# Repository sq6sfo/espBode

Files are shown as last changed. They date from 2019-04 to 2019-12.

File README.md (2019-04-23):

# espBode
Interface between a Siglent oscilloscope and FY6800 AWG

The idea bases on solution proposed by 4x1md in https://github.com/4x1md/sds1004x_bode

Currently implemented features:
 - ESP is able to connect to a selected WiFi network and listen to oscilloscope requests
 - After ESP sends request to AWG it waits for confirmation

TODO:
 - rewrite whole thing to C++, so adding new AWGs would be easier
 - add possibility to configure SSID/PSK + IP without flashing the new SW

**!WARNING! FY6800 VCC level is 5V, so it has to be dropped somehow to 3.3V ESP may release the magic smoke otherwise.**

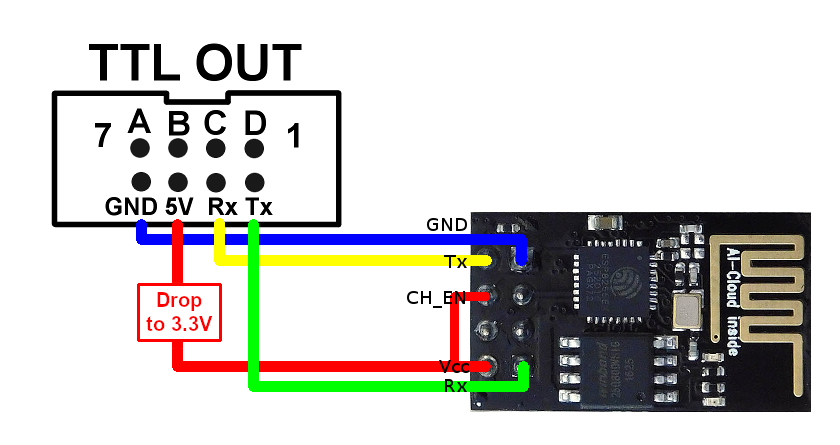
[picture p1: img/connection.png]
image test


In my configuration I've just used a yellow LED, that dropped the voltage by ~2V.
ESP consumes about 70mA, that's probably too much for a LED, but maybe it'll survive.

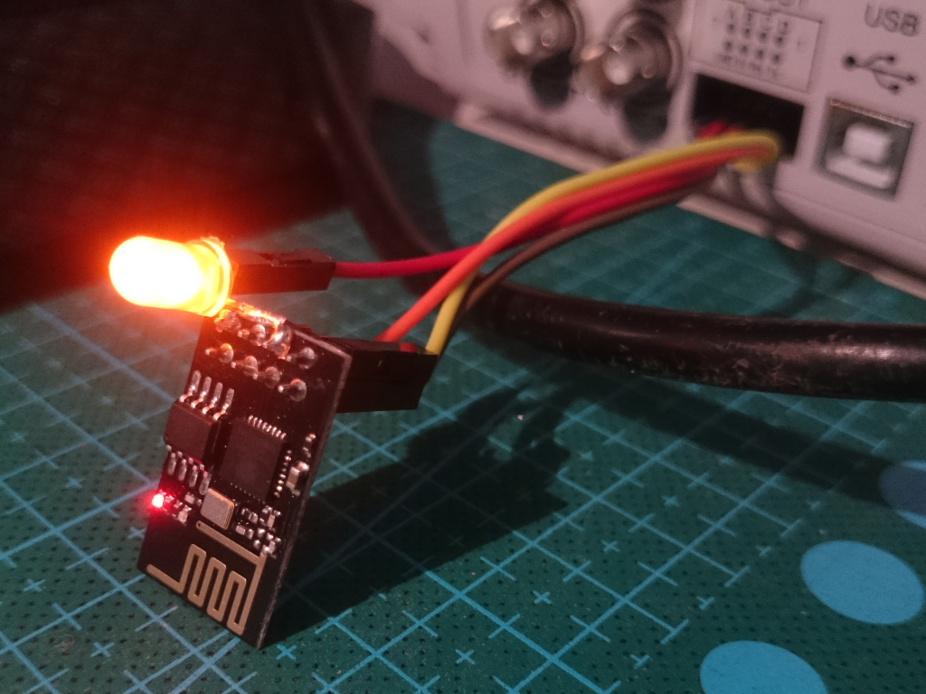
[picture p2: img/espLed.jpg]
image LED


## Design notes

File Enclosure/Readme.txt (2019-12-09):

3d printing instructions:
The enclosure consists of 3 parts.
  - The mounting plate for the ESP3266 adapter (with either heat stakes or M2x4 standoffs),
  - The actual enclosure to be used with M2x12 bolts.
  - The connector insert (has a tight fit but could also be crazy-glued to the mounting plate)

I recommend to use 0.1mm or smaller layer height so that the M2 thread is reasonably well reproduced.
The ESP adapter is cheaply available at Amazone, Banggood or Ali-Express at under $4 CDN delivered.
It has the necessary level shifters and 3.3V regulator on board an can be plugged in directly to the FY6800.
I used a small 1x4 female connector that snug fits into the printed connector insert on the bottom
side only so that the top 1x4 row of pins of the FY6800 just dangle without connection. A short ribbon
cable connects 1:1 with the adapter.

So far I am pretty happy with the current functionality developed by Jakub Stępniewicz and his collaborators.
There are a few glitches when you are operating the 8266 in AP mode. As it is not possible to connect to a static
scope ID, one needs to first make the scope use its DHCP to connect to the 8266. After that you need to switch
the scope back to static IP using the so found IP address. Havent found a smarter way of dealing with this issue.
But maybe someone has?

Another problem I found and currently investigate is with the FY6800's command for setting the amplitude. It is
correctly transmitted to the AWG but not recognized there.

Other than that, this is a great project and everybody's work on it greatly appreciated.
Keep up the good work! I may contribute more in the future as well :).

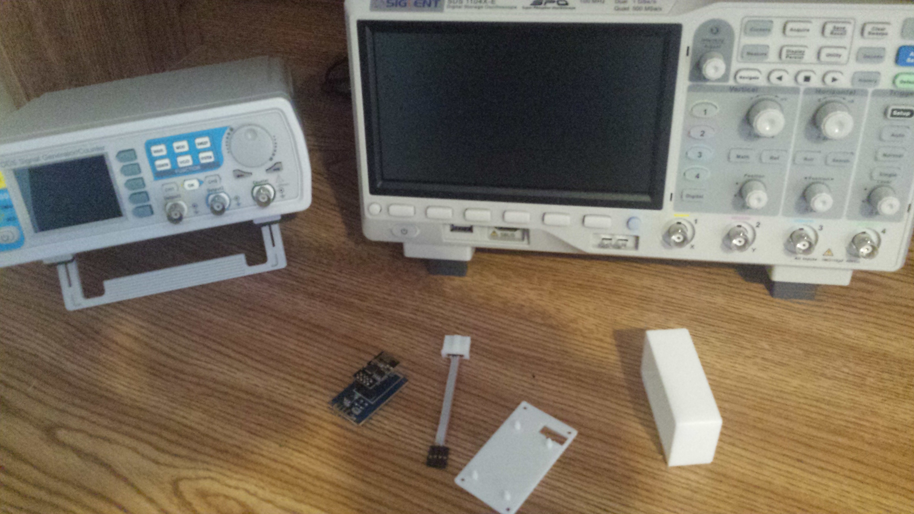
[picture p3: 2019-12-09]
Enclosure/SigFt1.jpg

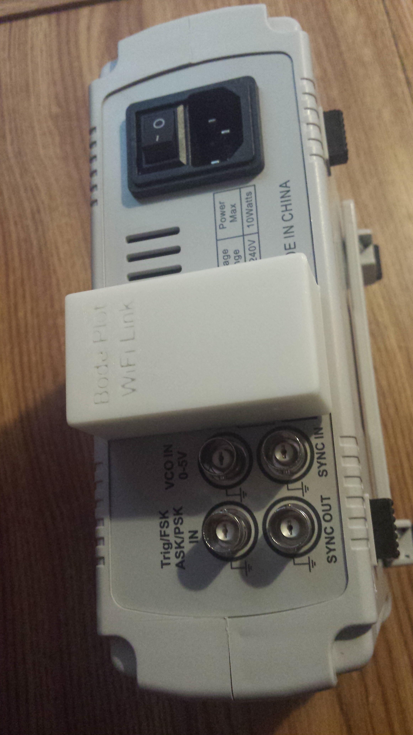
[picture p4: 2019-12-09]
Enclosure/SigFt3.jpg

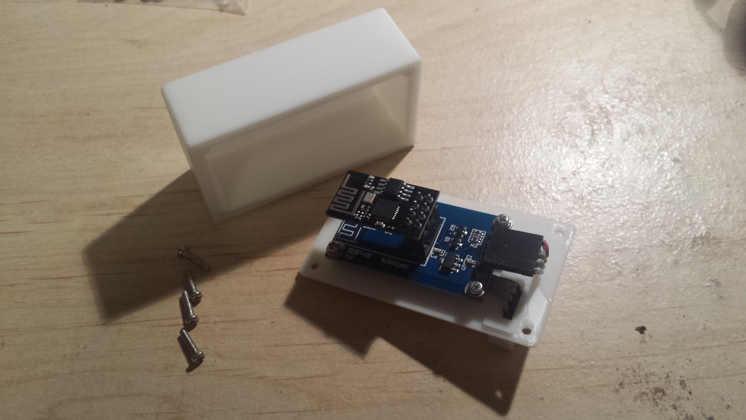
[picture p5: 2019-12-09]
Enclosure/SigFt4.jpg

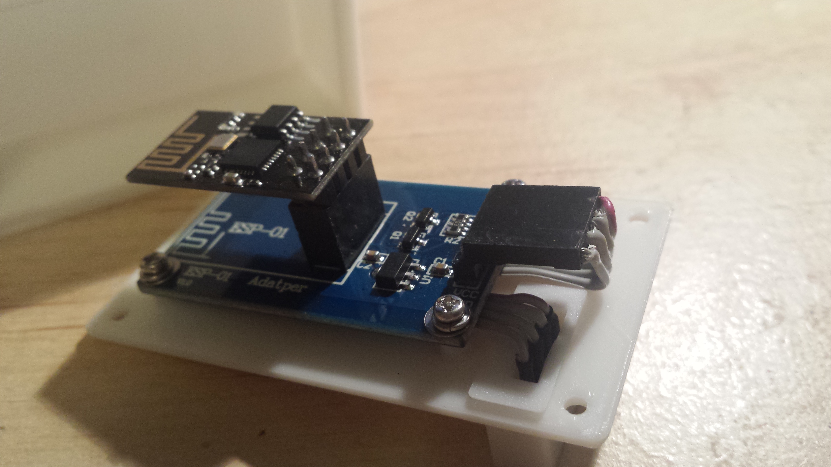
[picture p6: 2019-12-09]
Enclosure/SigFt5.jpg

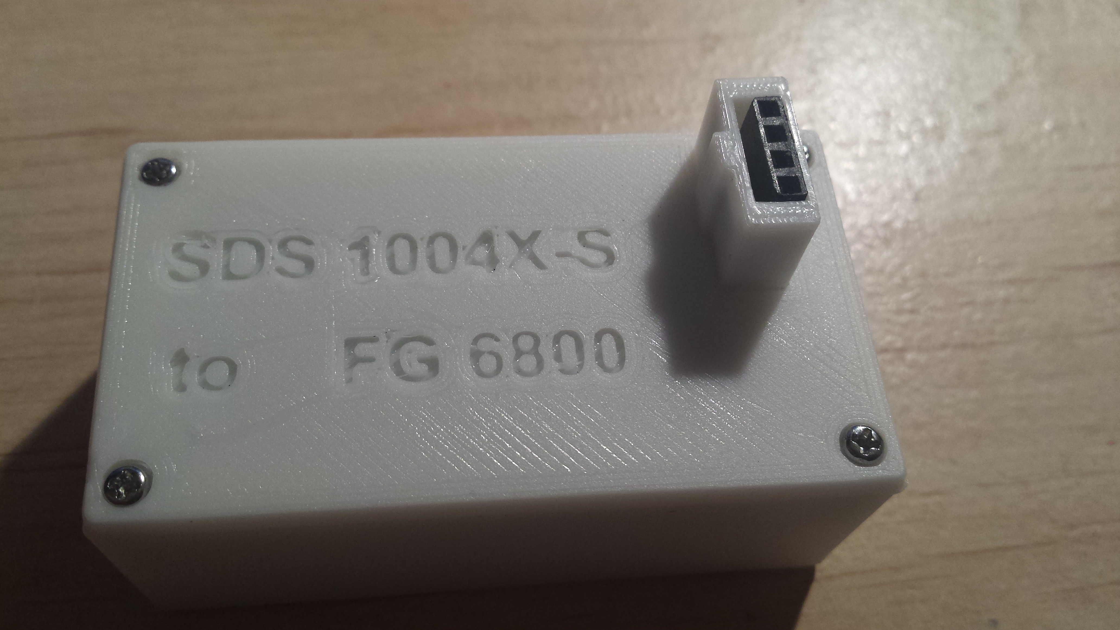
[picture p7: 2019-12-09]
Enclosure/SigFt6.jpg

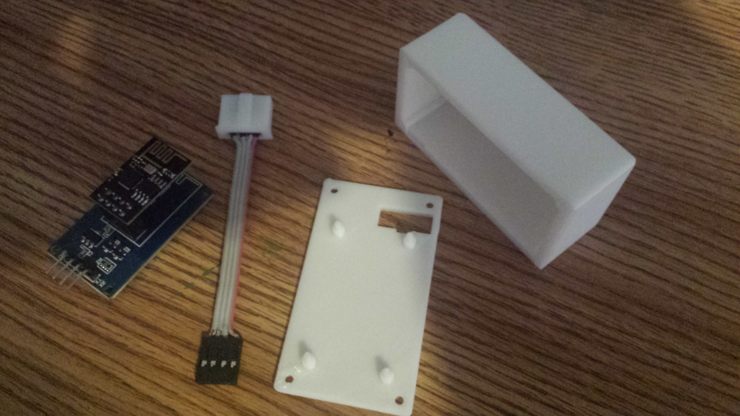
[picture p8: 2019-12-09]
Enclosure/SigFt2.jpg

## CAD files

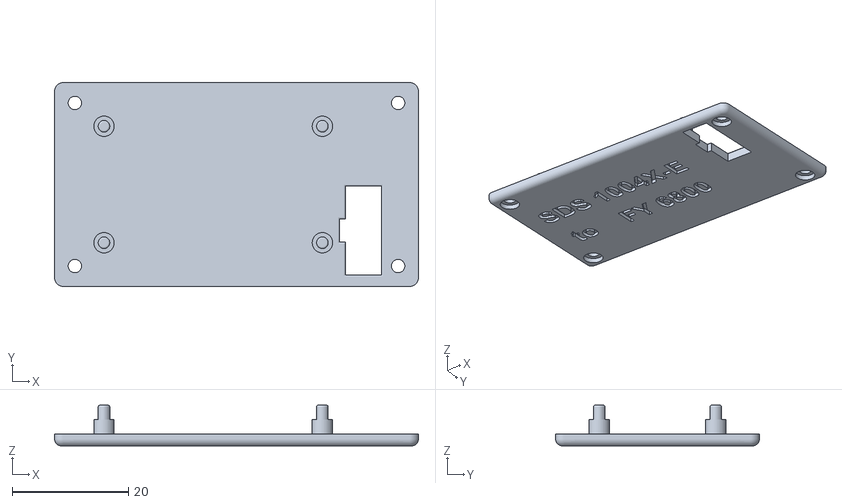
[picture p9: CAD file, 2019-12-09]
Enclosure/MountingPlate(heat stake).stl
62.5 x 35.0 x 7.00

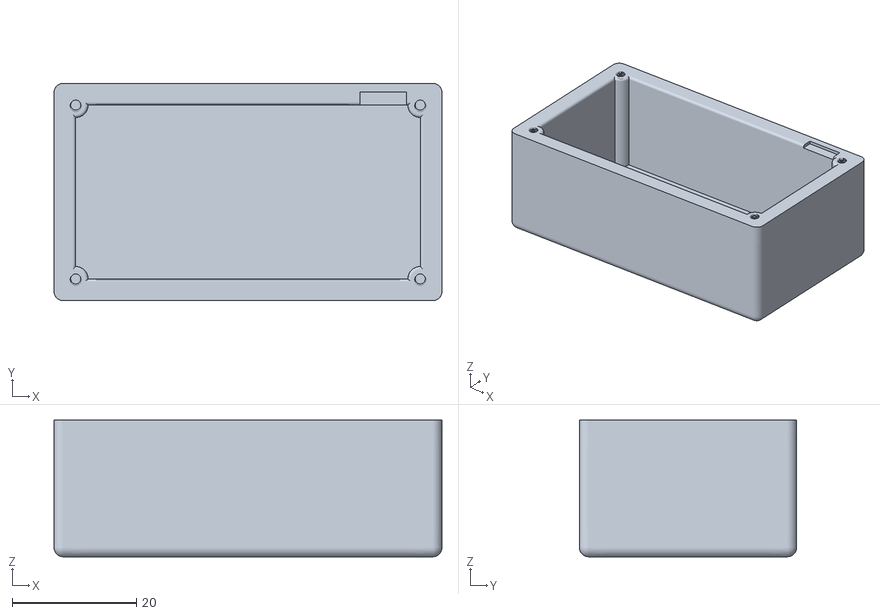
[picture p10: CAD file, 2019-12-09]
Enclosure/Enclosure.stl
62.5 x 35.0 x 22.0

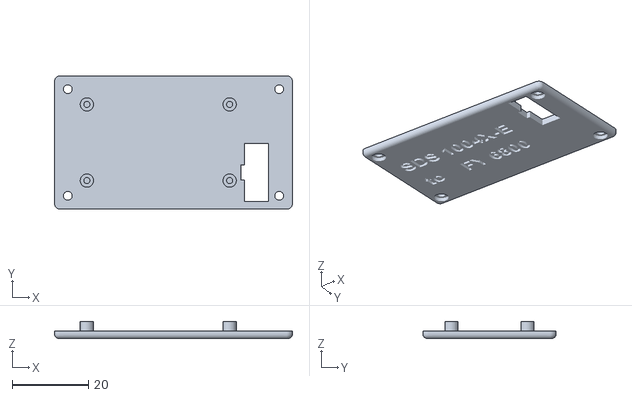
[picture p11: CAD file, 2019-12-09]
Enclosure/MountingPlate(M2x4).stl
62.5 x 35.0 x 4.50

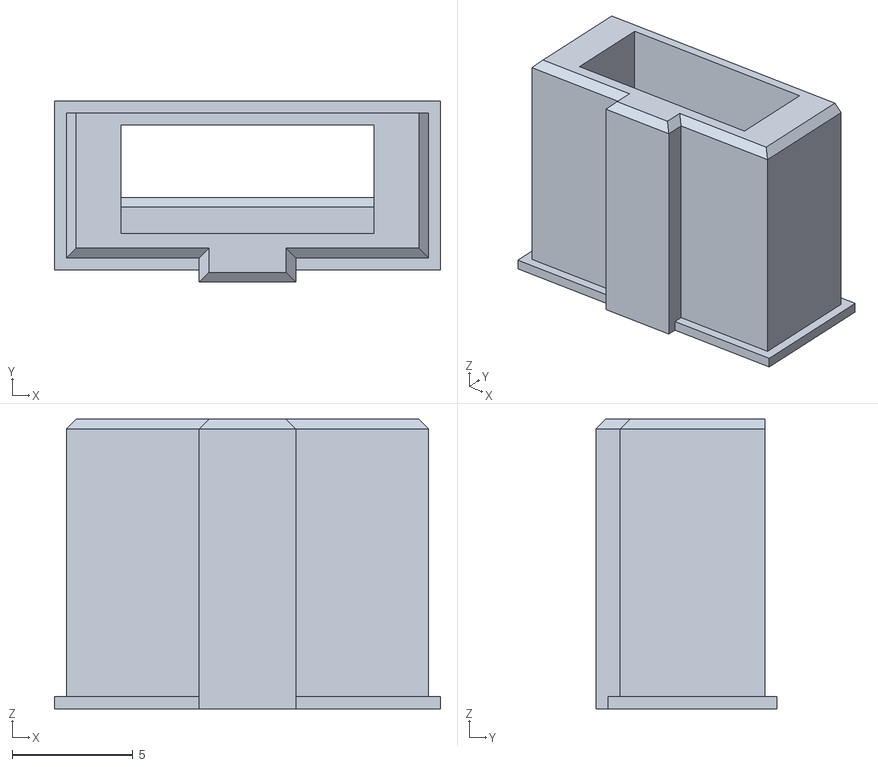
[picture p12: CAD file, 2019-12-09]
Enclosure/2x4Connector.stl
16.0 x 7.50 x 12.0

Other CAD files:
Enclosure/ESP8266_AWG v4.f3d

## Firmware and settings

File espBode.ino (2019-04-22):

#include <ESP8266WiFi.h>
#include "esp_network.h"
#include "esp_config.h"
#include "esp_fy6800.h"

WiFiServer rpc_server(RPC_PORT);
WiFiServer lxi_server(LXI_PORT);

void setup() {

    Serial.begin(115200);

    // We start by connecting to a WiFi network
    DEBUG("Connecting to ");
    DEBUG(WIFI_SSID);

#if defined(STATIC_IP)
    IPAddress ip(ESP_IP);
    IPAddress mask(ESP_MASK);
    IPAddress gateway(ESP_GW);
    WiFi.config(ip, gateway, mask);
#endif

#if defined(WIFI_MODE_CLIENT)
    WiFi.mode(WIFI_STA);
    WiFi.begin(WIFI_SSID, WIFI_PSK);
#elif defined(WIFI_MODE_AP)
    WiFi.softAP(WIFI_SSID, WIFI_PSK);
#else
    #error PLEASE SELECT WIFI_MODE_AP OR WIFI_MODE_CLIENT!
#endif

    while (WiFi.status() != WL_CONNECTED) {
        delay(500);
        DEBUG(".");
    }

    DEBUG("WiFi connected");
    DEBUG("IP address: ");
    DEBUG(WiFi.localIP());

    rpc_server.begin();
    lxi_server.begin();
}

void loop() {
    WiFiClient rpc_client;
    WiFiClient lxi_client;

    lxi_client.setTimeout(1000);

    do
    {
        rpc_client = rpc_server.available();
    }
    while(!rpc_client);
    DEBUG("RPC CONNECTION.");

    handlePacket(rpc_client);
    rpc_client.stop();

    do
    {
        lxi_client = lxi_server.available();
    }
    while(!lxi_client);
    DEBUG("LXI CONNECTION.");

    while(1)
    {
        if(0 != handlePacket(lxi_client))
        {
            lxi_client.stop();
            DEBUG("RESTARTING");
            return;
        }
    }
}

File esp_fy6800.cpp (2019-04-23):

#include "esp_fy6800.h"
#include <string.h>

volatile SDeviceState gDeviceState;

void fy6800_write(char* data, uint8_t len)
{
    uint32_t timeout = 0;
    Serial.write((uint8_t*)data, len);
    while(0 == Serial.available())
    {
        delay(1);
        if(timeout++>1000) return;
    }
    (void)Serial.read();
}

void setCh1Wave(EWaveType wave)
{
    char command[] = "WMW00\n";
    snprintf(command, 7, "WMW%02u\n", wave);
    gDeviceState.ch1Wave = wave;
    fy6800_write(command, 6);
}

void setCh2Wave(EWaveType wave)
{
    char command[] = "WFW00\n";
    snprintf(command, 7, "WFW%02u\n", wave);
    gDeviceState.ch2Wave = wave;
    fy6800_write(command, 6);
}

void setCh1Output(uint32_t output)
{
    if(output)
    {
        gDeviceState.ch1Output = 1;
        fy6800_write("WMN1\n", 5);
    }
    else
    {
        gDeviceState.ch1Output = 0;
        fy6800_write("WMN0\n", 5);
    }
}

void setCh2Output(uint32_t output)
{
    if(output)
    {
        gDeviceState.ch2Output = 1;
        fy6800_write("WFN1\n", 5);
    }
    else
    {
        gDeviceState.ch2Output = 0;
        fy6800_write("WFN0\n", 5);
    }
}

/* Set frequency in Hz */
void setCh1Freq(uint32_t frequency)
{
    char command[] = "WMF00000000000000\n";
    snprintf(command, 19, "WMF%08lu000000\n", frequency);
    gDeviceState.ch1Freq = frequency;
    fy6800_write(command, 18);
}

/* Set frequency in Hz */
void setCh2Freq(uint32_t frequency)
{
    char command[] = "WFF00000000000000\n";
    snprintf(command, 19, "WFF%08lu000000\n", frequency);
    gDeviceState.ch2Freq = frequency;
    fy6800_write(command, 18);
}

/* Ampl is in mV: 12.345V = 12345 */
void setCh1Ampl(uint32_t ampl)
{
    char command[] = "WMA00.000\n";
    snprintf(command, 11, "WMA%02u.%03u\n", ampl/1000, ampl%1000);
    gDeviceState.ch1Ampl = ampl;
    fy6800_write(command, 10);
}

void setCh2Ampl(uint32_t ampl)
{
    char command[] = "WFA00.000\n";
    snprintf(command, 11, "WFA%02u.%03u\n", ampl/1000, ampl%1000);
    gDeviceState.ch2Ampl = ampl;
    fy6800_write(command, 10);
}

/* Phase is in 0.1deg: 12.5deg = 125 */
void setCh1Phase(uint32_t phase)
{
    char command[] = "WMA00.000\n";
    snprintf(command, 11, "WMP%02u.%01u\n", phase/1000, (phase%1000)/100);
    gDeviceState.ch1Phase = phase;
    fy6800_write(command, 10);
}

void setCh2Phase(uint32_t phase)
{
    char command[] = "WFA00.000\n";
    snprintf(command, 11, "WFP%02u.%01u\n", phase/1000, (phase%1000)/100);
    gDeviceState.ch2Phase = phase;
    fy6800_write(command, 10);
}

void setCh1Offset(int32_t offset)
{
    char command[] = "WMO00.000\n";
    gDeviceState.ch1Offset = offset;
    if(offset>=0)
    {
        snprintf(command, 11, "WMO%02u.%03u\n", offset/1000, offset%1000);
        fy6800_write(command, 10);
    }
    else
    {
        snprintf(command, 12, "WMO-%02u.%03u\n", -offset/1000, -offset%1000);
        fy6800_write(command, 11);
    }
}

void setCh2Offset(int32_t offset)
{
    char command[] = "WFO00.000\n";
    gDeviceState.ch2Offset = offset;
    if(offset>=0)
    {
        snprintf(command, 11, "WFO%02u.%03u\n", offset/1000, offset%1000);
        fy6800_write(command, 10);
    }
    else
    {
       snprintf(command, 12, "WFO-%02u.%03u\n", -offset/1000, -offset%1000);
       fy6800_write(command, 11);
   }
}

void initDevice(void)
{
    Serial.write((uint8_t*)"\n", 1);

    setCh1Output(0);
    setCh1Wave(EWaveType_Sine);
    setCh1Freq(1000);
    setCh1Ampl(1000);
    setCh1Offset(0);

    setCh2Output(0);
    setCh2Wave(EWaveType_Sine);
    setCh2Freq(1000);
    setCh2Ampl(1000);
    setCh2Offset(0);

}

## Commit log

2019-04-16 Very first commit.
    Already working solution, tedted on ESP01 device.
2019-12-07 Add files via upload
    STL files for 3d printing and some photos.
    [2x4Connector.stl, Enclosure.stl, MountingPlate(M2x4).stl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]
2019-12-09 Add files via upload
    Corrected model names (oops)
    [MountingPlate(M2x4).stl, MountingPlate(heat stake).stl]
2019-12-09 Add files via upload
    This is the Fusion 360 CAD file for the enclosure.
    [ESP8266_AWG v4.f3d]
